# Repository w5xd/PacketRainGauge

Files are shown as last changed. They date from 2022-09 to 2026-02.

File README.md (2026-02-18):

# Packet Rain Gauge

This design is for a device that telemeters a packet when a magnet approaches, and
again when it retreats from a hall effect sensor. It consists
of a Printed Circuit Board (PCB) design, an Arduino sketch, and two variations on a funnel
that catches rain. One variant is a retrofit to install in a discarded rain gauge funnel
from an Oregon Scientific RGR126N Wireless Rain Gauge. If you don't 
have an RGR126N to retrofit, there is included  a 3D printable outdoor unit, which I designed
as a remix of this 
<a href='https://www.thingiverse.com/thing:4725413'>thingiverse rain gauge</a>.

This unit can telemeter to 
<a href='https://github.com/w5xd/PacketGateway'>an open-source packet gateway</a>.  Separately, or 
concurrently, this <a href='https://github.com/w5xd/WWVBclock'>WWVB clock</a> can monitor the packet
transmissions from this rain gauge. Or you derive your own design from the sources here. 

<h3>3D Print the Outdoor Assembly</h3>
The CAD directory in this repo has 3D 
models for the parts needed to all the outdoor parts.
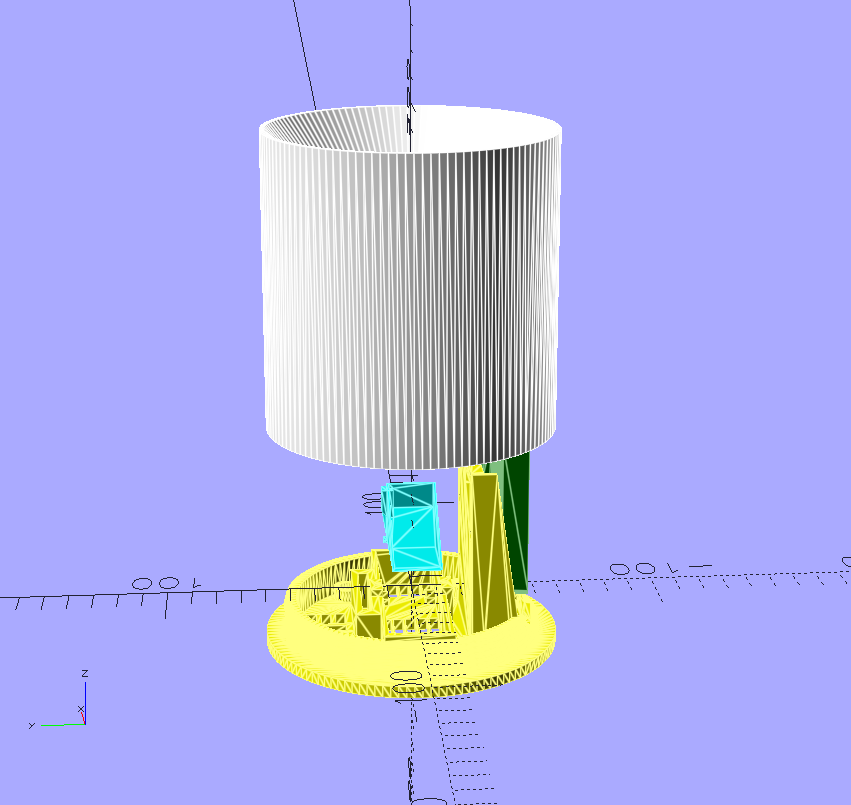
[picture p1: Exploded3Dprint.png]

STL files are downloadable from the <a href='https://www.thingiverse.com/thing:7052595'>thingiverse 7052595 posting of this remix</a>. 
All the STLs can be regenerated (or modified to your liking) using a combination of
OpenSCAD and FreeCAD. Each is open sourced and free.
The list of parts to print, starting with those designed with OpenSCAD is:
<ul>
<li><code>Pluviometer-base</code> (which requires the support enforcer <code>Pluviometer-base-supports</code>)</li>
<li><code>funnel-improved</code></li>
<li><code>Pluviometer-AA-print</code></li>
<li><code>bucket-improved</code></li>
<li>The flange I designed, <code>Pluviometer-flange-print</code>, fits snugly on the top of the T-profile steel fence post
I wanted to mount it. Unless you have the same fenceposts as me, you will have to use some other mount.
</li>
</ul>
The parts designed with FreeCAD are:
<ul>
<li><code>Placement-sensor enclosureBody001</code></li>
<li><code>Placement-sensor enclosureBody002</code></li>
</ul>

The PCB enclosure parts geometrically mate with both the Pluviometer-base, designed in OpenSCAD,
and the printed circuit board outline and hole pattern, which is available as a STEP model. The motivation for using FreeCAD
is that it can be configured to create a model that itself depends on both the OpenSCAD model of the base and bucket,
and the STEP model of the PCB. While the
FreeCAD method for a dependency on a STEP model is simply its File/Import method, FreeCAD has a not-quite-obvious
workflow for modeling dependencies on an STL mesh. Follow FreeCAD's File/Import of the OpenSCAD STL with
its Parts Workbench "Create Points From Geometry" method. The resulting points object can then be used
to create DatumPoint and DatumPlane references that can, in turn, be referenced in Sketches. The caveat is that this workflow
does not automatically accommodate subsequent changes to the OpenSCAD design. That is, any subsquent change in the OpenSCAD
design requires the FreeCAD model to be completely recreated manually.

<h3>Oregon Scientific Retrofit</h3>
The original Oregon Scientific rain gauge mechanical design is a funnel that directs rainfall into a rocker
that is centered below the funnel. The rocker (called a "bucket" in the thingiverse design) has two identical cups arranged on a see-saw. After 1mm
of rainfail, the higher cup has enough weight to rock the see-saw. The higher
one falls to become the lower one and dumps its water from the now lowered cup. The new position leaves 
the opposite
cup&mdash;which was empty&mdash;under the funnel. It begins to fill with new rainfall and the process repeats. In the middle of the
rocker&mdash;centered, which means it does not affect the center of mass between the two cups&mdash;is a magnet. 
The PCB detects the magnet swinging
by. 

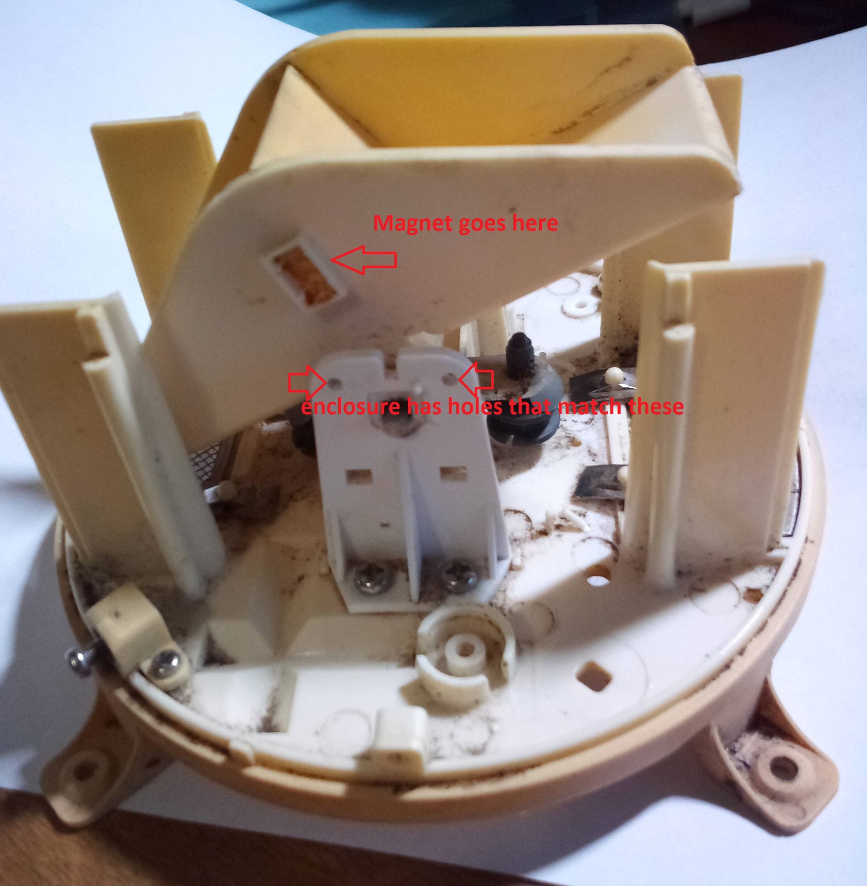
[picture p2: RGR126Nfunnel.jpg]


The RGR126N design sensed the passing of the magnet using a reed relay. Such a relay has ferro magnetic 
contacts that close as
the magnet is in proximity. The original relay sensor was positioned for closest approach 
to the relay
as the rocker passed top dead center
in both directions, which means the rocker was moving relatively quickly as the relay sensed it.  

A hall effect magnetic sensor is used in this design instead of a reed relay. The Si7210
version of the PCB, sketch, and sensor can
easily be programmed to separately detect the arrival and the departure of the magnet from
proximity to the sensor. (A non-programmable AH1383 sensor can be substituted.)
The geometric desgin positions the sensor
in close alignment with the rocker <b>at its resting position</b> with one
cup down&mdash;the left one in the photo above. Its Arduino
sketch is programmed to separately report the arrival and departure of the rocker, sending a packet for
each. The new magnet is mounted in the same recess in the rocker as the old magnet. 
The needed magnet is slightly heavier than the original: about 0.5g as
opposed to 0.3g on my scale, so a calibration check is in order before putting it into service.
The result is this design sends packets at (almost) the same rate per volume of rainfall
as the old one, just not quite at the exact same rocker positions.

Silicon Labs publishes a detailed discussion about magnets&mdash;including details
about this exact scenario: replacing a reed relay with a hall effect sensor&mdash;about how the
magnet axis and sensor geometry are related: 
<a href='https://www.silabs.com/documents/public/application-notes/an1018-si72xx-sensors.pdf'>
https://www.silabs.com/documents/public/application-notes/an1018-si72xx-sensors.pdf<a>.
A K&J Magnetics B422 magnet conveniently matches the original magnet's dimensions to
fit in the original rocker, and has its
poles aligned so that its
pole axis as required to penetrate the IC sensor when mounted in the original rocker.

The original water tight
battery compartment is retained, but after removing the PCB that shares the
battery enclosure. This upgrade runs on two AA cells just like the original. I had
no luck running the Oregon Scientific device using lithium AA cells, but this design works
well with them and gets the much longer battery life with the lithium cells'
 much larger Ampere-hour capacity compared to alkaline.

This retrofit parts list is:
<ul>
<li> The original funnel's plastic parts minus the two PCBs, and with the
original magnet removed from the rocker. It was glued in place and a small screwdriver can pry it out.
<li> The PCB as documented in this repository. It mounts the Arduino, 
a TMP175 sensor, and an RFM69 packet radio module. Gerber files are <a href='./PCB'>here</a>.
<li> A <a href='https://www.kjmagnetics.com/proddetail.asp?prod=B422'>K&J Magnetics B422 neodymium magnet</a>. 
dimensions are 1/8" x 1/8" x 1/4" which fit into the same mounting hole on the original rocker.
Note there is a required orientation of the new magnet that takes some care when
you glue it. See <a href='#MAGNET_ORIENTATION'>below</a>.
<li> A 3D printable enclosure that mounts on the same hole pattern
as the one of the original PCBs&mdash;the one facing the magnet on the rocker.
<li> Two AA cells inside the original plastic battery compartment. The
battery's original ribbon cable is replaced with just a pair. +3VDC and GND wires are routed 
to the replacement PCB. This design can use either
alkaline or lithium cells. 
</ul>

<h2>Arduino sketch</h2>
The <a href='PacketRainGauge/PacketRainGauge.ino'>sketch</a> sends a packet to the Packet Gateway every time the 
magnet on the rocker arm either arrives at, or departs from the
sensor. The message
packet also contains a battery voltage measurement, the TMP175
reading, and other details. The sketch also sends a packet after
a timed interval absent any rainfail, which enables battery level
monitoring at the gateway. The timed interval is settable, and
once per 24 hours is enough. The temperature reading at the funnel is 
useful mainly for
monitoring the condition of the funnel assembly. Direct
sunlight on the funnel makes its value not representative
of ambient air temperature because the funnel must be 
mounted in the open to be useful as a rain gauge.
<br/><br/>
The gateway's processing of the rainfall messages is not part of this
repository. See the repository at https://github.com/w5xd/diysha for
an example. In that project, the receipt of rainfall packets writes a
text file that, in turn, can be read by the "bins" feature in <a href='http://www.gnuplot.info'>gnuplot</a>.

<h2> Construction</h2>
Both variations use the same electronics and custom PCB.
The <a href='https://www.sparkfun.com/products/11114'>Arduino Pro Mini</a> requires the 
following of its hardware options to be made in order to work 
in this project:
<ul>
<li>The 3.3V version of the Pro Mini is <b>required</b> (<i>i.e.</i> not the 5V version.)
<li>Jumper SJ1 (top side, close to the GND pad) must be desoldered to remove the red power LED's power drain.
<li>The bottom side i2c pullup positions, R1 and R3, can each have a 4.7K 
resistor installed. Two SMD 0603 size resistors just fit inside a hole
in the PCB designed to clear them. Alternatively, REV02 and higher of the PCB has positions for SMD
0805  pull up resistors that are not quite so tiny.
</ul>

PCB Parts for PCB version 3 and later
<ul>
<li>Sparkfun Arduino <a href='https://www.sparkfun.com/arduino-pro-mini-328-3-3v-8mhz.html'>Pro Mini</a> in 3.3V
<li>Sparkfun <a href='https://www.sparkfun.com/rfm69hcw-wireless-transceiver-915mhz.html'>
RFM69HCW</a></li>
<li><a href='https://www.silabs.com/documents/public/data-sheets/si7210-datasheet.pdf'>Si7210-B-04-IVR</a> I2C Hall effect sensor in SOT-23-5 package or...<br/>
<a href='https://www.mouser.com/datasheet/3/175/1/AH1381_AH1382_AH1383.pdf'>Diodes Incorporated AH1383</a> in SOT-23-5</li>
<li><a href='https://assets.nexperia.com/documents/data-sheet/74HC_HCT1G86.pdf'>SN74HC1G86</a> Single 2 input XOR in SOT753 package</li>
<li><a href='https://assets.nexperia.com/documents/data-sheet/74HC_HCT1G02.pdf'>SN74HC1G02</a> Single 2 input NOR in SOT753 package</li>
<li><a href='https://assets.nexperia.com/documents/data-sheet/74HC_HCT1G14.pdf'>SN74HC1G14</a> Single Schmidt inverter SOT753 package</li>
<li>TMP175 temperature sensor in 8 SOIC package
<li>10M resistor size SMD 1206
<li>2.7K resistor size SMD 1206
<li>2 by 4.7K resistors size SMD 0805
<li>3 by 10uF 10V tantalum or ceramic in SMD 1206
<li>.1uF ceramic 16V in SMD1206
</ul>

Mouser <a href='https://www.mouser.com/Tools/Project/Share?AccessID=1e16e65a5d'>Project</a> referencing all the above PCB parts.

<h3>Si7210 end-of-support and the AH1383</h3>
Silicon Labs has announced end of support for the Si7210. The Diodes Incorporated AH1383
is supported as a substitute on the PCB and sketch. It solders onto the same pads as the Si7210, except
the SDA/SCL lines for I2C have no connection to the AH1383.
The AH1383 happens to fit on the same solder pads as the si7210.

<h3>PCB considerations</h3>
Mount the Arduino directly to the PCB without headers. 
To ensure the pads on the Arduino do not connect to the vias on the PCB, cut a piece
of paper roughly .3" wide and 1" long. Insert this paper as an insulator between
the Pro Mini and the PCB while soldering header terminals between the PCB and
the Arduino. It may be left in place or pulled out after soldering

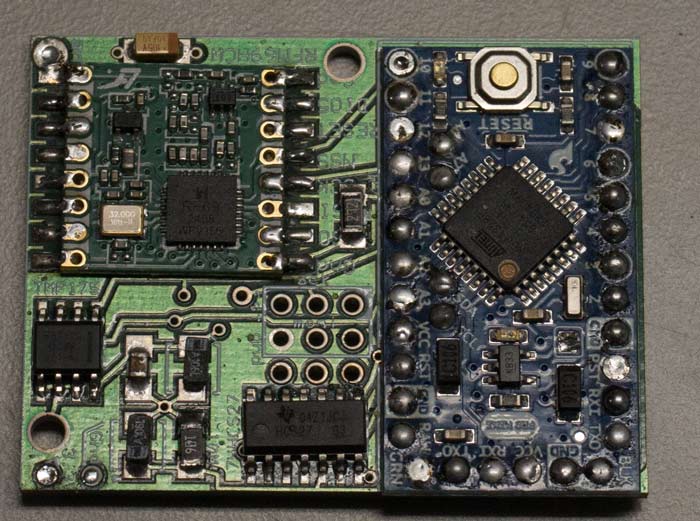
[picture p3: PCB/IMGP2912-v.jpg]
PCB top


Its important to:
<ul>
<li>center the Arduino on its holes in order to clear the I2C resistors mounted as above. 
<li>minimize the solder bumps on the bottom side of the PCB so the assembly will 
fit in the enclosure. I set the PCB on a flat surface, laid the Arduino board on top,
then inserted headers from the top and soldered from the top first, so the pins just
reach the bottom of the main PCB.
</ul>

The replacement PCB layout is optimized to be as small as possible while 
retaining the ability for an ordinary human to place the parts and solder them.
I used a <a href='https://whizoo.com/'>home brew SMD oven</a>, but steady hands can alternatively 
solder them one pin at a time.

The PCB circuit diagram is <a href='PCB-circuit.pdf'>here</a>.

The hall effect sensor is mounted to the <i>bottom</i> of the PCB. (REV01 shown, later revisions
look similar.)
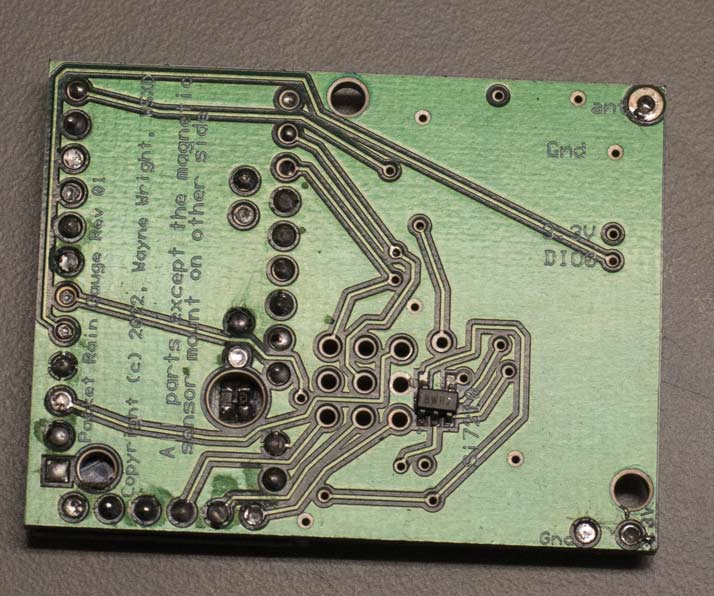
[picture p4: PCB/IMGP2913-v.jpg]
PCB bottom

This is the only part on the bottom.
I used an SMD oven to mount it first (and nothing else in the oven with it.) After it cooled off, 
I flipped the board over
and used the oven again to bake the top side SMD parts. While the ExpressPCB process provides
a solder paste mask in its gerber files, I found it easier just to use a very small stick of some sort
(a 0.050" allen key, for example) to dab tiny bits of paste on the solder pads.
The RFM69 is documented to be
oven-safe, but I have destroyed at least one (maybe not because of the oven?) and its
easy enough to hand solder its 100 thou wide solder pads.
<br/><br/>
Setting up the Arduino requires programming the part, and also requires 
serial port commands to configure the radio parameters.  Connecting to the Pro Mini's
serial port is a bit of a trick because the enclosure cannot accommodate a standard
0.100" header soldered onto the board. One option is to solder on a header, program
the sketch, set its parameters through the same serial port header,
 and then cut the header off to install the Arduino in its enclosure.
Alternatively, the PCB has
 a hole pattern that enables  a pogo adapter to access either 
the standard ISP
programming header on the Arduino Pro Mini, or, in a non-standard layout, the
Arduino's serial port.

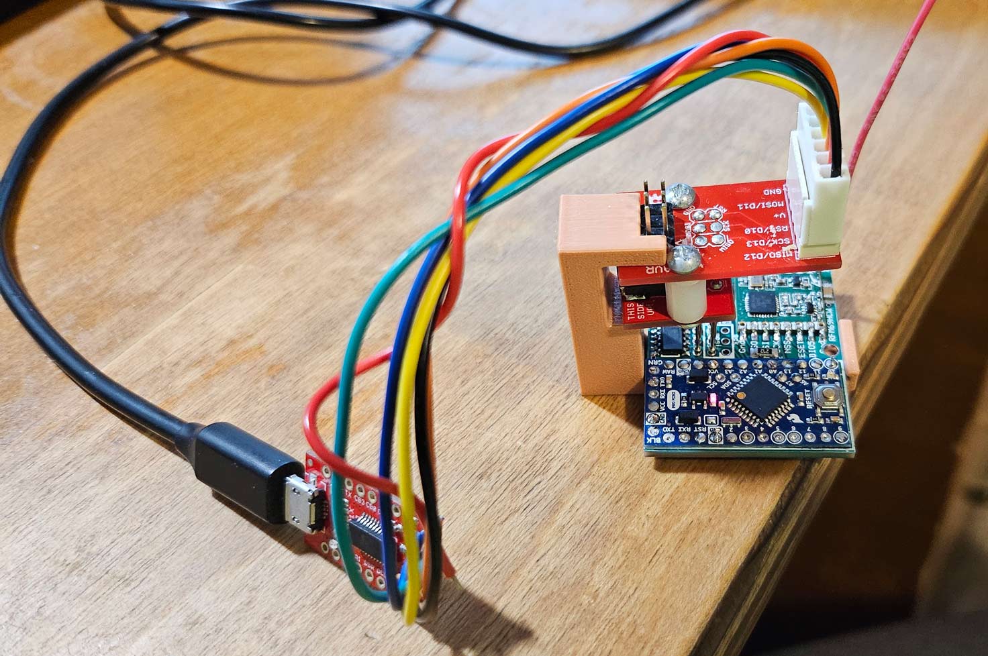
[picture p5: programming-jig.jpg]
programming-jig


The serial port pin layout on this PCB is 3 extra pins alongside the standard 6-pin ISP header.
I custom assembled a <a href=''>SparkFun ISP Pogo Adapter</a> with an FTDI USB serial breakout
to access the Arduino serial port this PCB. It can be used both to program
the CPU, and to set its configurable parameters. Be sure
you wire the 3.3VDC to the pogo! The RFM69 will be destroyed if you 
apply 5VDC.

Position the serial port pogo
on the 6 pins aligned along the nearest edge of the PCB, and it connects to the Arduino's
serial port pins. The Pogo adapter as supplied
has no connector on the ends of its wires. You can solder them to, for example,
the <a href='https://www.sparkfun.com/products/13263'>SparkFun FT231X Breakout</a>.
Note that on this particular FT231X breakout, you <b>must</b> change the power jumper to
make it supply 3.3V, else you'll fry the RFM69 on your first try.

The CAD directory has a 3D model for a jig that fits the PCB and the Pogo adapter
that frees your hands while accessing the serial port on the PCB.

The Pogo Adapter has 6 wires. When positioned for access to the Arduino serial port,
the wires are <i>not</i> as labeled on the Pogo board, but are as follows on the PCB's
Arduino:
<ol>
<li>black. 3.3VDC. <i>Not</i> 5V, which will destroy the RFM69.
<li>red. MOSI. Leave open. Only 5 wires are connected for serial port access.
<li>orange. GND
<li>yellow.  RXI on Arduino. To TXD on break out.
<li>green. TXO on Arduino. Goes to RXI on break out.
<li>blue. DTR on Arduino. DTR on the break out.
<li>To match the Arduino-to-Serial-breakout standard wiring, you also must put a
jumper directly on the break out between its ground and CTS.
</ol>

A Pogo adapter wired as above to a serial break out can be used both to
program the Arduino, and to use a terminal application for serial port
commands to configure the packet radio parameters. A different Pogo 
adapter can also be used posititioned to its standard wire assignments
to program the Arduino on its ISP port, but the radio parameters
can only be configured through the serial port.

<h3>Enclosures</h3>
Both PCB enclosure designs, the retrofit and the full outdoor unit, have a two
part 3D printable shell to house the custom PCB. 
For the retrofit, its base has three mounting holes matching the original rocker-mounted PCB. 
For either design, there are three holes
for these wires: one each for the radio antenna, ground, and 3.3V. 
Once the Arduino is configured, use a silicon sealant
on the joints between the base and cover, and also to seal the wire holes.
Consider the enclosure as disposable. If you use a silicon rubber sealant,
you might be able to use a box cutter to open it if you need to reprogram
the Arduino. But plan to 3D print a replacement enclosure should you ever
open it.
On the retrofit, I substituted #4 brass wood screws for the original steel screws that held
the PCB inside the funnel assembly, because I suspected that the strong
magnet attraction on them might chage the mechanical balance of the rocker
 and thus change the calibration.
<br/><br/>
The full outdoor unit needs the following commercially available parts to house
the dual cell AA battery:
<ol>
<li> <a href='https://www.mouser.com/ProductDetail/12BH222-GR'>Eagle Devices 12BH222-GR</a>. If you try to substitute a 
part be careful
with the width. The 12BH222 is comparatively narrow, and
just fits inside the AA holder 3D printed part.
<li>Quantity two by AA cells. Lithium cells are preferred. They should last over 12 months.
<li> A <a href='https://www.kjmagnetics.com/proddetail.asp?prod=B422'>K&J Magnetics B422 neodymium magnet</a>.
The same part as the retrofit, above. Note there is a required orientation of the magnet that takes some care when
you glue it. See <a href='#MAGNET_ORIENTATION'>below</a>.
<li> <a href='https://www.mcmaster.com/catalog/131/4021/2418T16'>3/32" width, Dash Number 141 O Ring (2 1/2" OD)</a>
The O ring seals the battery compartment against water.
<li> Quantity 7 #3-48 x 3/8" socket head screw. (#2-56 x 3/8" socket head also fits the 3D print)
<li> Quantity 7 #3-48 hex nuts. (#2-56 nut also fits the 3D print)
<li> The base/flange mount 3D parts have holes for quantity four #8-32 x 3/4" socket head screws and matching 8-32 hex nuts
</ol>

When assembling the two enclosure halves together (Body001 and Body002) with the PCB in between as a 
sandwich, it shoud not be possible to squeeze them tightly enough to permanently actuate the RESET switch
built into the Sparkfun Arduino Pro Mini. But check it. It won't telemeter and it will run
down the battery in about 24 hours.

<h3 id="MAGNET_ORIENTATION">Magnet Orientation</h3>
The B422 magnet's 1/4" dimension fits into the rocker mount in the obvious 1/4" slot dimension. 
But that constraint still leaves
four 1/8" sides of the magnet that might face the sensor. <b>Only one works. The
South pole of the magnet must face the sensor!</b>
(well, the Si7210 can be programmed to work if the North pole is instead facing
the sensor.) The magnet must be chosen and positioned to exceed the turn ON threshold
of the sensor.
<a href='MagnetOrientation.md'>See details here.</a>

<h3>How many signals per inch of rain?</h3>
The original Oregon Scientific part, by my observation, sends an update every 1mm of rainfall. In the retrofit,
I measured the device to send an update about every 1.2mm of rainfall. I attribute the difference
to the extra weight of the B422 magnet compared to the original (as nothing else has changed.)
The full outdoor unit, as <a href='https://www.thingiverse.com/thing:4725413'>documented by its original designer</a> 
clicks every 0.15mm of rain. As of the latest update to this repository, a 1/4" hex weighting nut is added
to the rocker to make the water volume more consistent, and to require more water to rock it. 
I measure 0.38mm of rain per click. Your mileage may vary. 
<br/><br/>
What is the highest rainfall rate that can be telemetered? There are at least two different
parts of this design that might limit the highest rate: (a) water pouring through the funnel
so fast that it rocks the bucket by force of the pouring water instead of the designed behavior, which
tips the bucket when only the weight of the water in the upper bucket overcomes the weight of the empty bucket,
and (b) the electronics has a fastest rate it can detect movement (the sensor manufacturer documents
it at 5 samples per second) or telemeter it (the RFM69 packet
radio.) I have not attempted to measure either of these, nor brainstorm any additional rate limits.
However, I have measured that the on-the-air length of a packet is under 3 milliseconds. 
And I have observed that the system reliably telemeters 1 packet every 3 seconds as the calibrated cylinder
calibration test begins.
The actual limit is likely much faster than that.  A bucket dump every 3 seconds
corresponds to a rainfall rate of about 7 inches per hour. 
If your raingauge
experiences more than 7 inches per hour and you are in the vicinity, then you have more serious problems than 
whether your raingauge can keep up.

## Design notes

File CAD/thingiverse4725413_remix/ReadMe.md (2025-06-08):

This is a modified version of https://www.thingiverse.com/thing:4725413

My magnet of choice is of dimensions 1/4" x 1/8" x 1/8" as described in 
this repo's root directory.
My sensor of choice is the hall effect as described in this repo's root directory.

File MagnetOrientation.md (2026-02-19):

<h1>Magnet Orientation</h1>
The B422 magnet has two faces perpendicular to its pole axis and I'll call the other two
"sideways." Another
magnet with known poles can figure out which face is right: the face that sticks to 
the other magnet IS one of the poles. Here
are some more hints: <a href='https://www.kjmagnetics.com/products.asp?cat=163'>
https://www.kjmagnetics.com/products.asp?cat=163</a>.  For the AH1383, the South pole
must face the PCB.
<br/><br/>
You can also use the assembled
PCB and sketch to read out the magnetic field with the magnet close. When oriented properly,
it will read the maximum negative magnitude about +16000. 
Use the sketch's <code>ReadModeForSeconds</code> command to
make the magnetic field print out continuously. Hold the magnet directly over the Si7210 and then
slide it only 1/8" or so in the 2 directions perpendicular to the magnet.
If you have a pole directly facing the sensor (the 
desired orientation) the sign will not change on the magnetic field. If you have a unipolar
sensor (AH1381) with the correct (South) pole, facing it, stays at +1 at (nearly) equal distances in
all directions from centered over the sensor. With the wrong pole, it reads out 0 and nothing happens at all
as you move the magnet away from the center of the sensor.
If you have an edge toward
the sensor ("sideways"), the sign will change right where the magnet is centered over the sensor. 
The AH1383
version of the sketch also supports the <code>ReadModeForSeconds</code> command, but it
only reads out +1 (for the magnet "close") and 0 for the magnet "far." You need the magnet
oriented so its reads +1 on the AH1383 when centered over the sensor.

<h2>AH1383 thresholds: 45 Gause on, 35 Gause off</h2>
The Si7210 version of this build is especially useful for experimentation because the sketch can
be set for a wide range of on and off thresholds and can be made to operate either omnipolar
or unipolar. However, that part might not be available. The AH1383 has built in thresholds,
on at 45 Gause, and off at 35 Gause, which must
be compatible with the actual magnetic fields of the chosen physical magnet and geometery.
This section describes that calculation. <br/><br/>
The 3D printed rocker and sensor are spaced with the magnet and sensor about .15 inches apart
along the N/S axis of the magnet, which is the Y dimension in the graph below. The rocker moves
the magnet between two positions at X = 0 (magnet and sensor aligned) to about X = .42 inches
where the rocker rests against the opposite stop. The magnetic field calculations are from  
<a href='https://www.kjmagnetics.com/magnetic-field-calculator.asp'>https://www.kjmagnetics.com/magnetic-field-calculator.asp</a>.
Here is what the magnet/sensor geometry looks like for a properly installed magnet and with the
rocker directly under the magnet:
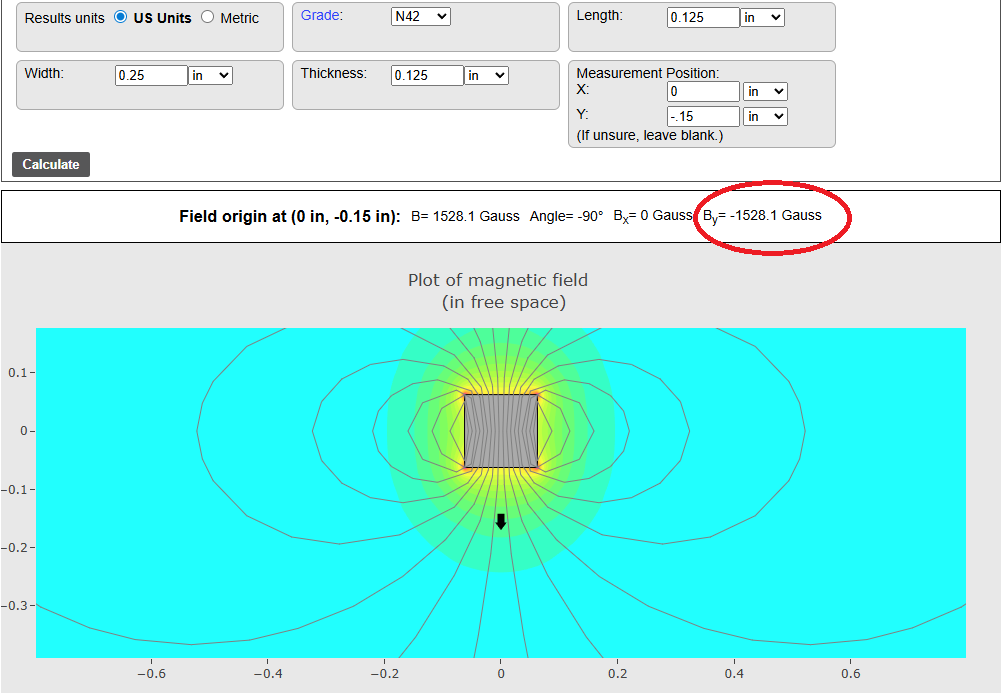
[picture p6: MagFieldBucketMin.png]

The next graph below shows that this particular magnet need move only a few thousanths of an inch around the
point X=.177 inches for the B<sub>Y</sub> field shift signs, which is where the
amplitude moves through both the ON and OFF thresholds of the part. X=.177 is not quite half
way through the rocker movement with top dead center at X=.42/2 = 0.21 inches. With the magnet installed properly
the sensor position is indicated by the arrow in the screen shots, and the magnet on
the rocker moves left and right across the field as graphed here.
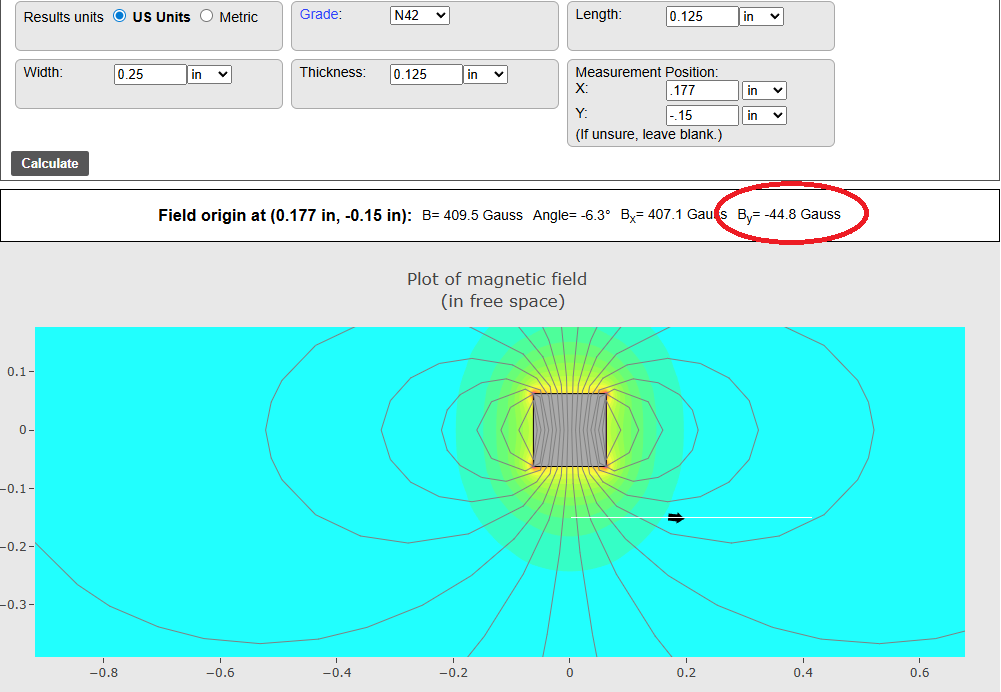
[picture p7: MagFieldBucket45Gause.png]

The AH1383 is unipolar, which is important because with the rocker at the far stop, as 
shown below, 
the amplitude of the magnetic field has magnitude above the 35 or 45 Gause threshold,
but of the opposite sign. (Parts specified as "omnipolar" will trigger above a
threshold amplitude of either sign. They won't work here.)
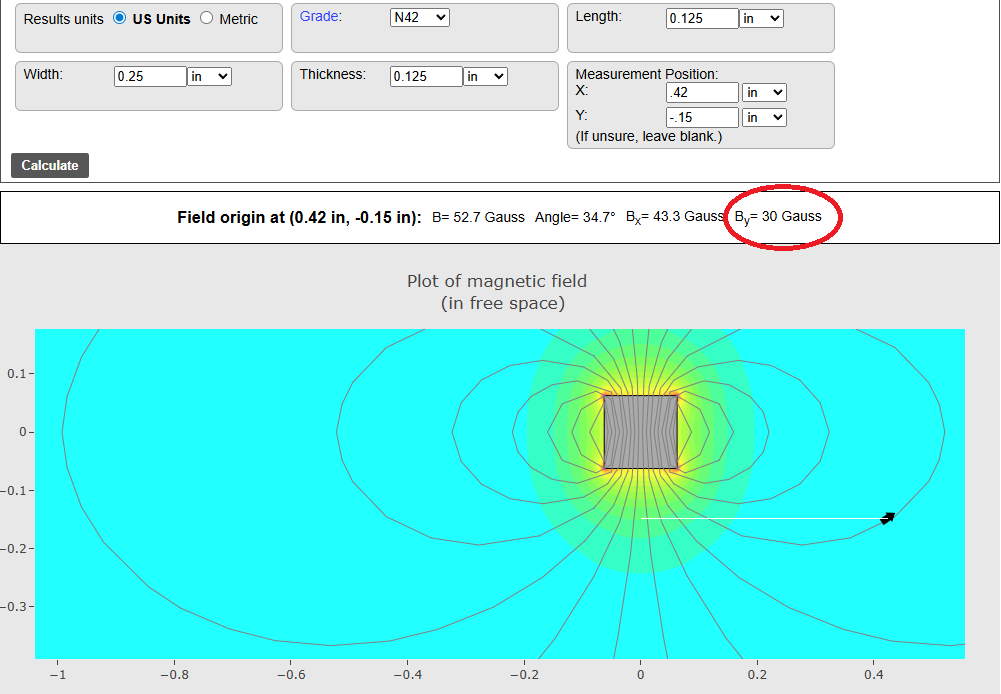
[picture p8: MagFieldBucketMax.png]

As can be seen from the graphs above, the parts AH1382 and AH1381 are suitable substitutes
for the AH1383 specified for this build. The -82 and -81 parts have smaller thresholds,
but, because all the parts in this series are unipolar, and because the field is of opposite
polarity on opposite ends of the rocker travel, all the parts should work and
will switch states very close to the X=.177 point where the field polarity reverses. 
A backwards magnet will get the same field amplitudes, but in opposite polarity, which
means only the AH1381 has any hope of turning on, and then only when the magnet is
as far as possible from the sensor. Backwards won't work.
<h4>Sideways magnet calculation</h4>
The field calculator can also be used to predict what will happen if the magnet is incorrectly
installed
"sideways." Spoiler alert: it won't work. Sideways means the magnet is with its N/S pole axis along 
the face of the rocker as opposed to facing
the sensor. To calculate that behavior, reverse the X and Y everywhere they appear in the calculator. 
The sensor position in this graph is at the arrow as in the graphs above, but moves up and down as the rocker moves.
The calculator predicts zero amplitude B<sub>X</sub> at X=0 (not graphed--the answer is zero),
peaking at about X=0.1 inch 
with about 700 Gause (also not graphed), and dropping down to about 40 Gause at the far rocker rest stop of X=0.42.
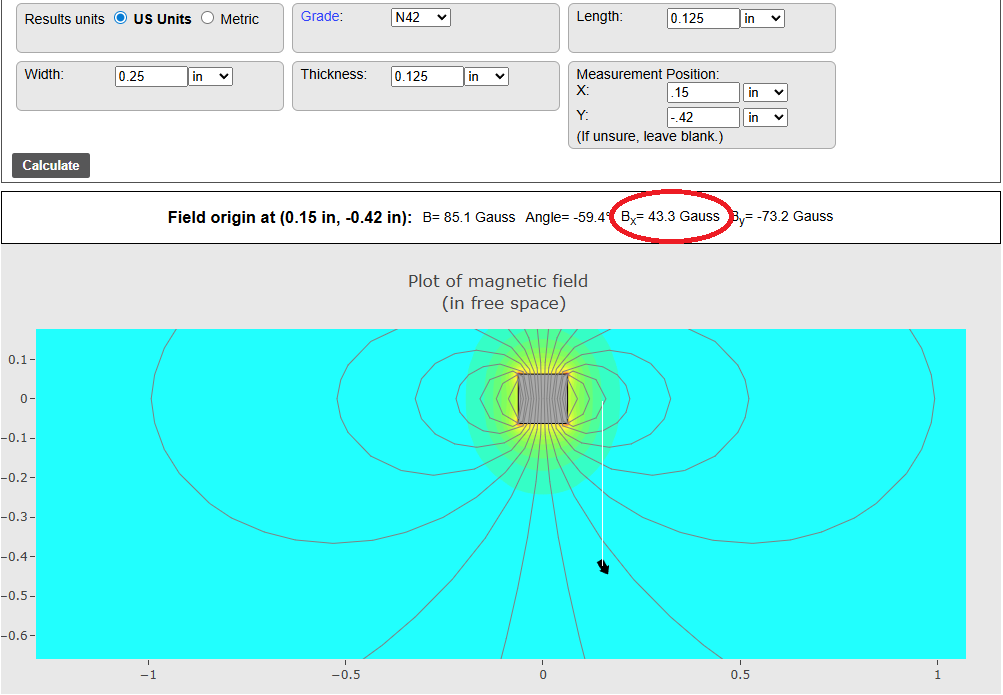
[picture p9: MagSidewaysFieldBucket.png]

Slight movement of the rocker around X=0 will move the field both above the ON threshold and below the
OFF threshold. Therefore, multiple redundant signalling the rocker around X=0 can be expected. This
applies to both possible incorrect sideways orientations. (Only the polarity of the field at the
sensor is reversed with respect to the other sideways orientation.)
<h2>Sketch parameter setup</h2>
All the magnetic field calculations in the previous section apply to the Si7210, but
the Si7210 and its sketch have many programmable settings for 
thresholds and polarity. That is, the Si7210 can support
a much wider range of magnet strengths and geometry. In the physical designs presented here, it means
smaller magnets can be used than specified, and the N/S axis orientation can work in two
directions, rather than just the one that the AH1383 must see.
Th sketch parameter advice here applies to both physical arrangements, the Oregon Scientific funnel retrofit, and 
3D printable design presented here. 
<ul><li>Mount the magnet with either its N
or S pole facing the sensor as described in the previous section.</li>
<li>The recommended Si7210 interrupt threshold and hysteresis settings are a relatively
low magnitude (1500 out of a maximum of 16000) and small hysteresis (8 out of 1792). The commands
are:
<pre>
<code>SetSWOP 0x64
SetSWHYST 0
</code></pre></li>
<li>The Si7210 interrupts per the previous item, but the chip's interrupt output does not
directly correspond to the magnet position. The sketch, therefore, is coded to originate
a notification of a rocker move based on the magnetic field going outside the range
specified as below. 
<pre>
If the North pole faces the sensor:
<code>SetNearThreshold 1500
SetFarThreshold 0
SetSignedThreshold 0
</code>If the South pole faces the sensor:<code>
SetNearThreshold -1500 <i>Note it is negative</i>
SetFarThreshold 0
SetSignedThreshold 1
</code>
</pre>
The NearThreshold and FarThreshold are signed, and need to be different based on the
magnet orientation. The OP and HYST values in the Si7210 are not signed, and do not
depend on the magnet orientation.
</li>
</ul>
The sketch, per the above settings, is waked up by any motion of the magnet around the value 1500,
and then polls the magnetic field looking for it to go outside the range NearThreshold and FarThreshold.

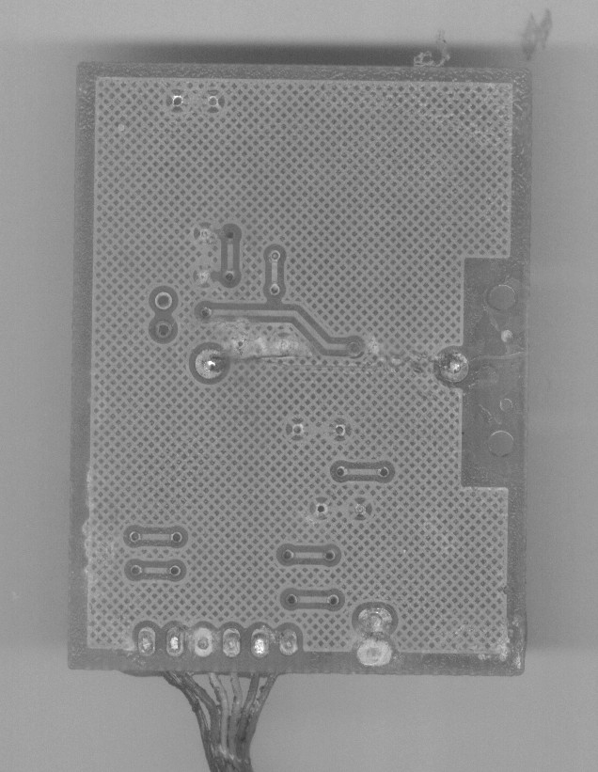
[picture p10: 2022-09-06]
CAD/rain-funnel-sensor.jpg

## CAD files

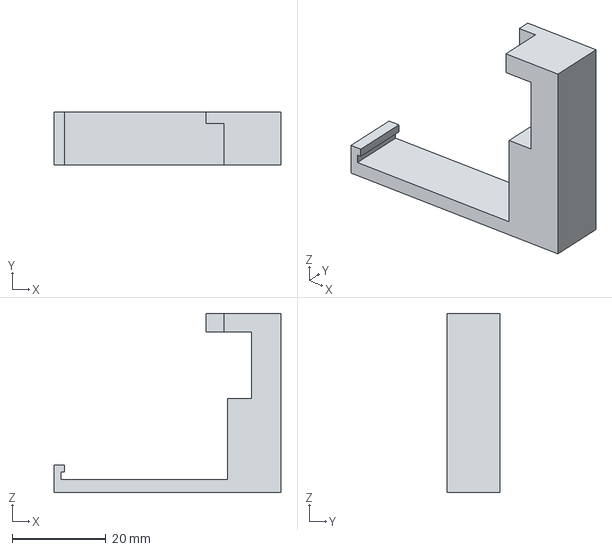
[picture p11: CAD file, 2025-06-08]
CAD/jig-PartBody.step
48.5 x 11.4 x 38.4 mm

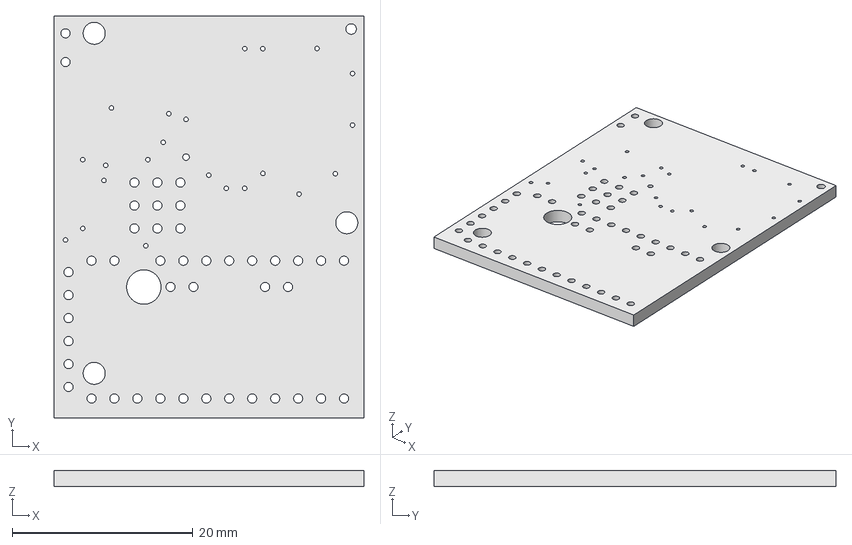
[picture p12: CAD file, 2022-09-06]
CAD/pcb-Body.step
34.3 x 44.5 x 1.78 mm

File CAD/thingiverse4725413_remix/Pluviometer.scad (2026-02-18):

/* This thing is modified from https://www.thingiverse.com/thing:4725413
** (c) 2025 by Wayne E Wright, https://www.thingiverse.com/wwrr55 
**
** The sources to the 3D models, the Arduino sketch, 
** the printed circuit board, etc. are published on github at https://github.com/w5xd/PacketRainGauge
** The 3D printable STL files are published on thingiverse (and not on github).
**
** While the overall structure of the 4725413 scad file, Pluviometer.scad, is retained, none of the parts
** here is compatible with printed versions of the original. Each has been modified in
** some way from the original.
**
** The bucket is modified to accept a different magnet, 1/4" x 1/8" x 1/8"
** The threaded base/funnel joint is now implemented with the standard threads library: https://github.com/rcolyer/threads-scad
** The sensor and sensor_back are removed this implementation.
** The base is modified to have a built-in dual AA cell battery bracket.
** AA cell holder to match the bracket is added.
** A flange to mate a certain T-post steel fence post is added.
**
** A companion FreeCAD file contains a design to place a hall effect sensor PCB
** at the base's sensor slot.
*/
use <threads.scad>

cable_holder = false;

view_as_assembled = 1; // [1:as assembled, 0:expoloded, 2:XZ cross section, 6:XZ' cross section, 3:YZ cross section, 4:3D print, 5:intersect base&AA]
show_base = true;
show_base_supports = false;
show_flange = false;
show_cellAACover = true;
show_bucket = true;
show_funnel = true;

funnel_height_mm = 120;
funnel_inner_height_mm = 70;
funnel_tip_id_mm = 5; //[0.1:.1:10]
funnel_tip_wall_thick_mm = 1; // [0.1:.1:5]
funnel_strainer_z_thick_mm = 0; // [0:.1:3]
funnel_strainer_horz_thick_mm = 1; // [0:.1:3]

base_diameter_mm = 120;

number8MachineScrewBoltHoleDiameter = 25.4 * .18;
number8MachineScrewSocketHeadDiameter = 25.4 * .285;
number8MachineScrewSocketHeadHeight = 25.4 * .17;
number8MachineNutHeight = 25.4 * .135;
number8MachineNutAcrossFlats = 25.4 * 11 / 32;

base_funnel_thread_diameter_mm = 105;
base_funnel_thread_height_mm = 14;
base_funnel_thread_pitch_height_mm = 2.5;
base_mount_hole_diam_mm = number8MachineScrewBoltHoleDiameter;
base_disk_thickness = 5;

bucket_width = 70;
bucket_z_height = 25; // [22:.1:40]
bucket_display_rotation = 0;
bucket_inner_triangle_fill_width = 25;
bucket_inner_triangle_fill_height = 15;
bucket_hex_insert_flat_mm = 0.1; // 11.1 for 1/4" nut
bucket_hex_thickness_mm = 5.5;
bucket_hex_surround_mm = 1.1;

fnval = $preview ? 12 : 120;
fn30val = $preview ? 10 : 30;
$fn = $preview ? 12 : 120;

module __x__ () {} // stop the OpenSCAD customizer here

bucket_slot_width_mm = 24;
bucket_y_width_mm = 20;
bucket_z_thickness_mm = 1;
bucket_y_thickness_mm = 1;
bucket_x_thickness_mm = 1;

flange_start_z_mm = -23;
flange_fastener_diameter_mm = 18;
flange_fastener_height_mm = 3;
flange_transitionmm = 25.4 * 1.5;
flange_post_overlap = 25.4 * 1.5;
flange_post_cut_depth = 25.4 * 2;

tan30squared = tan(30) * tan(30); // for converting nut "across flats
acrossFlatsConvert = sqrt(1 + tan30squared);

module triangleRa(a, angle, h, c){
  rotate([90, 0, 0])
  linear_extrude(height = h, center = c, convexity = 10)
  resize([a, a*tan(angle)])
  polygon([[0,0], [1,0], [0,1]], paths=[[0,1,2]]);
}

module triangleI(x, y, z, c){
  rotate([90, 0, 0])
  linear_extrude(height = y, center = c, convexity = 10)
  resize([x, z])
  polygon([[-1,0], [1,0], [0,1]], paths=[[0,1,2]]);
}

module bucket_hex(outer = true)
{
  if (bucket_hex_insert_flat_mm > 1)
  {
    n = 6;
    inc = 360 / n;
    hex = [for (s=[0:1:n-1], a = (inc/2) + s * inc) [cos(a), sin(a)]];
    r = (bucket_hex_insert_flat_mm * 0.5 / hex[0][0]);
    translate([0,-(bucket_y_width_mm-bucket_hex_thickness_mm-bucket_hex_surround_mm)/2, bucket_z_height - r - 3*bucket_hex_surround_mm])
    rotate([90,0,0])
      {
        if (outer)
        linear_extrude(h=bucket_hex_thickness_mm + bucket_hex_surround_mm, center=true)
          offset(bucket_hex_surround_mm) 
            polygon(hex * r);
        else
        translate([0,0,bucket_hex_surround_mm])
          linear_extrude(h=bucket_hex_thickness_mm + bucket_hex_surround_mm, center=true)
            polygon(hex * r);
     }
  }
}

module bucket(){
  one4 = 25.4 * .25;
  one8 = one4 * .5;
  magClearance = .008 * 25.4;
  magY = bucket_y_width_mm/2 - 1;
  magZ = 18;
  color("cyan")
  difference(){
    union(){
      bucket_hex(true);
      difference(){
        triangleI(bucket_width, bucket_y_width_mm, bucket_z_height, true);
        translate([-bucket_width/4-bucket_x_thickness_mm/2, 0, (bucket_z_height+bucket_z_thickness_mm)/2]) 
          cube([bucket_width/2, bucket_y_width_mm-bucket_y_thickness_mm*2, bucket_z_height-bucket_z_thickness_mm], center = true);
        translate([bucket_width/4+bucket_x_thickness_mm/2, 0, (bucket_z_height+bucket_z_thickness_mm)/2]) 
          cube([bucket_width/2, bucket_y_width_mm-bucket_y_thickness_mm*2, bucket_z_height-bucket_z_thickness_mm], center = true);
      }
      // centering the bucket
      linear_extrude(height=1)
        square([5, bucket_slot_width_mm-.9], center=true);

      // magnet outer
      magOuterDx = one8 + one8;
      magOuterDy = one8 + one8/2;
      magOuterDz = one4+one8;

      magOuterYZProfile=[[magOuterDy/2, -magOuterDz/2], 
                [magOuterDy/2, magOuterDz/2],
                [-magOuterDy/2, magOuterDz/2],
                [-magOuterDy/2, -(magOuterDz + one4 + one8)/2]];
      translate([0, magY + one8/4, magZ])
      rotate([90,0,90])
      linear_extrude(height=magOuterDx, center=true)
          polygon(magOuterYZProfile);
    
      triangleI(bucket_inner_triangle_fill_width, bucket_y_width_mm, bucket_inner_triangle_fill_height, true);

      }
    
    // pivot shaft hole
    translate([0, 0, 3]) rotate([90, 0, 0]) cylinder(d=3.25, h=bucket_y_width_mm, center=true, $fn=fn30val);
    bucket_hex(false);
    // magnet inner
    translate([0, magY, magZ])
    translate([0,one8/2])
      cube([one8 + magClearance      , one8+.05       , one4 + magClearance], center=true);
  }
}

// AA battery holder dimensions
/* The profile of the AA cell holder is 58mm x 26mm
  ** The O-ring of choice is 3/32" diameter (or .103" = 2.6mm) 
  ** The minimum Oring circumference, keeping it just outside the cell holder profile, is then 
  **  (58+5.2 + 29+5.2) * 2 = 188.8 mm, diameter = 60.1mm, = 2.366"
  ** Choose Dash Number 141, which is 2 1/2" OD. The circumference corresponding to the mean of the OD, ID is
  **     191.5 mm is the circumference of the oring
  ** To get to the actual profile, make the straight sides match the cell holder dimension:
  ** Remainder = 191.5 - (2 * (58 + 29)) = 17.5mm
  **  radius of a circle for that circumference is:  2.785mm
  */ 
  batt_holder_z_offset = 6;
  batt_holder_top_z_mm = 75;
  batt_holder_start_y_mm = 22; // will mirror to -y axis
  batt_holder_end_y_mm = 41;
  batt_holder_end_x_mm = 27;
  batt_holder_Ythick_mm = 5;
  batt_holder_Xthick_mm = 2;
  batt_holder_ywidth_mm = 10;
  batt_holder_brace_z_thick_mm = 14;
  oRingRadius = .103 * 25.4 * .5;
  cellFastenerDx = 6 * oRingRadius;
  AAcellW = 29;
  AAcellH = 58;
  oRingCellHolderRadius = 2.785;
  // 2 * (AAcellW + AAcellH) + 2 * pi * oRingCellHolderRadius = length of (i.e. circumference of) oring

  batt_holder_YZ_profile = [[batt_holder_start_y_mm, 0], 
                            [batt_holder_start_y_mm, batt_holder_top_z_mm],
                            [batt_holder_start_y_mm+batt_holder_ywidth_mm, batt_holder_top_z_mm],
                            [batt_holder_end_y_mm, batt_holder_brace_z_thick_mm],
                            [batt_holder_end_y_mm, 0]
                            ];

 
  batt_holder_XY_profile=[[batt_holder_end_x_mm, batt_holder_start_y_mm],
                          [batt_holder_end_x_mm, batt_holder_start_y_mm + batt_holder_Ythick_mm],
                          [-batt_holder_end_x_mm, batt_holder_start_y_mm + batt_holder_Ythick_mm],
                          [-batt_holder_end_x_mm, batt_holder_start_y_mm]];


/* number 2
  cellFastenNutHeight = .06 * 25.4;
  cellFastenBoltHoleDiameter = .09 * 25.4;
  cellFastenNutAcrossFlats = (3 / 16) * 25.4;
  cellFastenDriverClearanceDiameter = .13 * 25.4;
  cellFastenSocketHeadDiameter = .175 * 25.4;
  */

/* number 3 */
  cellFastenNutHeight = .07 * 25.4;
  cellFastenBoltHoleDiameter = .105 * 25.4;
  cellFastenNutAcrossFlats = .1865 * 25.4; // one thousandth's too small for tight fit
  cellFastenDriverClearanceDiameter = .115 * 25.4;
  cellFastenSocketHeadDiameter = .175 * 25.4;
/* */  

/* number 4 
  cellFastenNutHeight = .1 * 25.4;
  cellFastenBoltHoleDiameter = .12 * 25.4;
  cellFastenNutAcrossFlats = (1/4) * 25.4;
  cellFastenDriverClearanceDiameter = .145 * 25.4;
  cellFastenSocketHeadDiameter = .195 * 25.4;
  */

  minXFastener = -cellFastenerDx;
  minYFastener = -cellFastenerDx;
  maxYFastener = AAcellH + cellFastenerDx;
  maxXFastener = AAcellW + cellFastenerDx;
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

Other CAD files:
CAD/jig.FCStd

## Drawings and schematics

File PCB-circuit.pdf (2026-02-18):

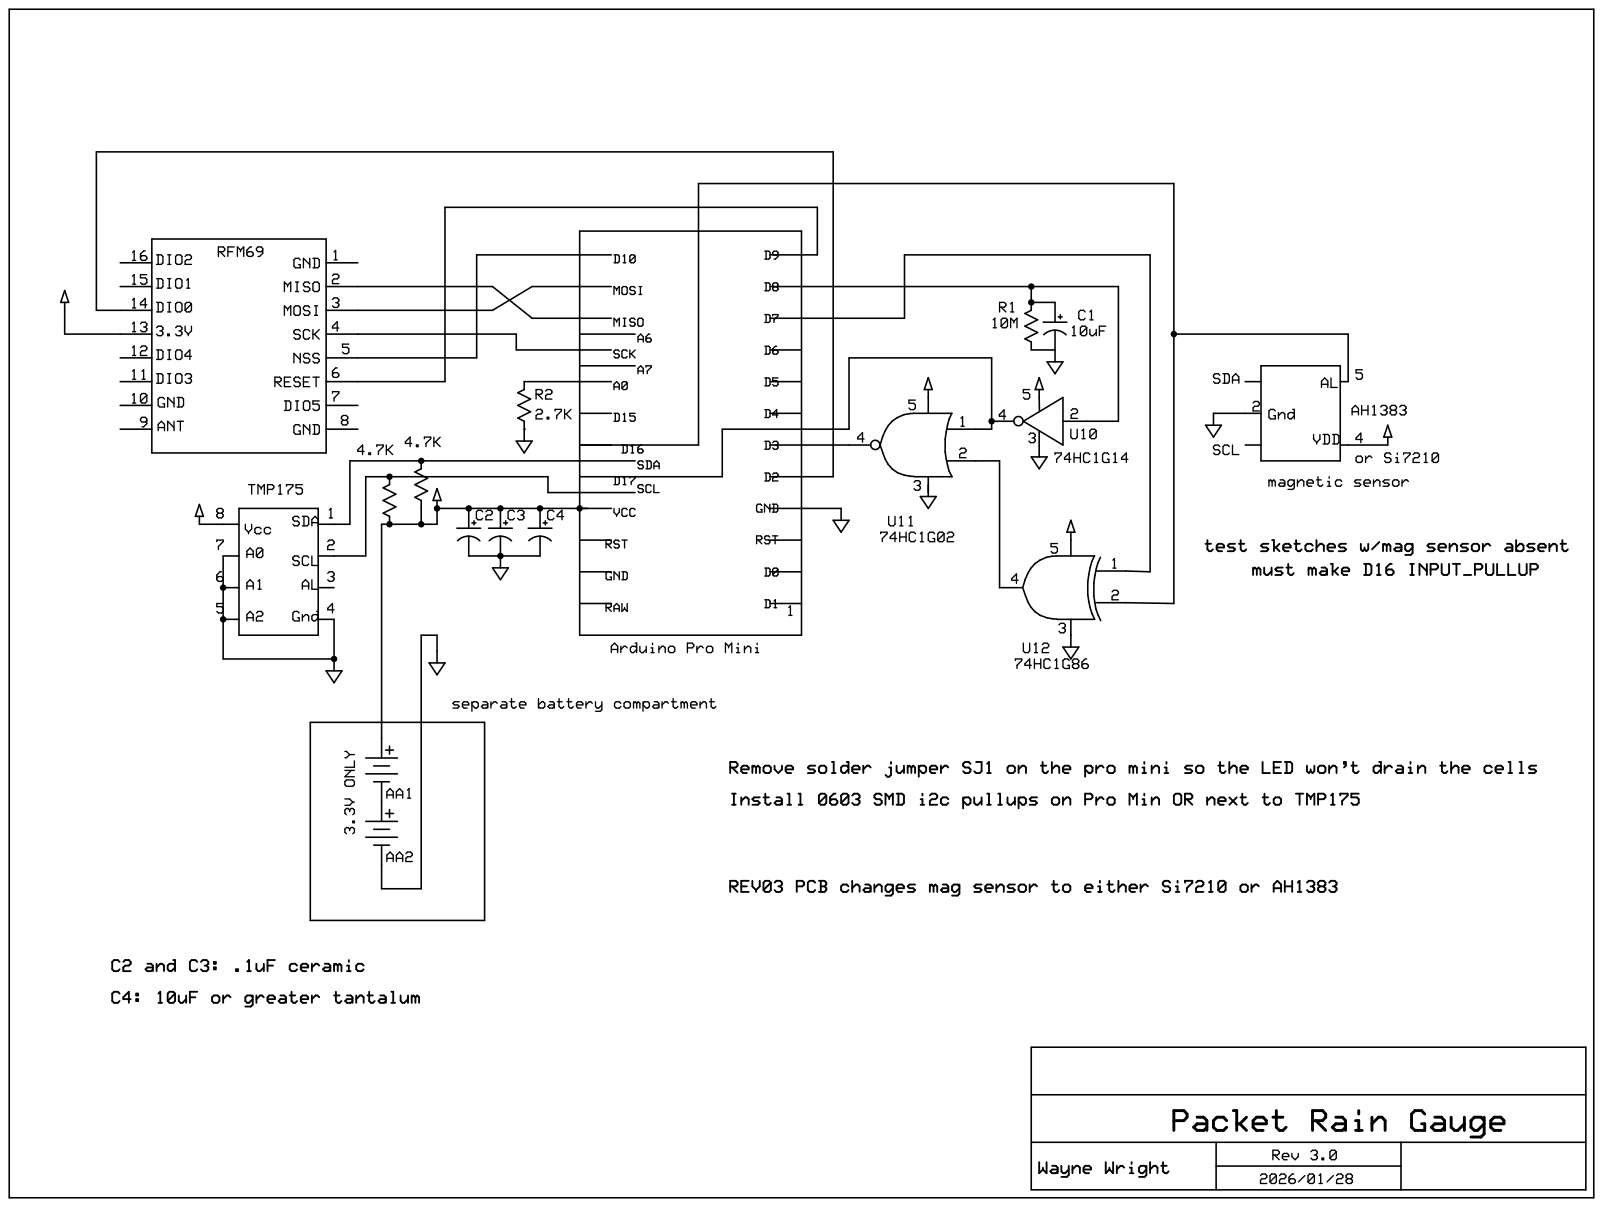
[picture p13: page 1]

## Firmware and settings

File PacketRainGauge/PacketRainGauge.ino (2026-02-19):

/* Packet rain gauge
* This sketch is to run on a Pro Mini on a PCB with a hall effect magnet sensor.
* It originates a packet for both the arrival and departure of a magnet
* to its sensor. The usual application is to mount a magnet on
* a rocker under a rain gauge funnel.
* 
* This design also reports a temperature from a TMP175 sensor and a battery 
* voltage level. It also originates packets on a timed interval in the absence of rainfail.
*/

#include <RadioConfiguration.h>
#include <SPI.h>
#include <EEPROM.h>
#include <Wire.h>
#include <avr/sleep.h>
#include <avr/interrupt.h>
#include <avr/power.h>
#include <RG-Si7210.h>
#include <RG-Tmp175.h>

// SparkFun's part numbers are:
// 915MHz:  https://www.sparkfun.com/products/13909
// 434MHz:  https://www.sparkfun.com/products/13910

// Parts of the code in this sketch are taken from these sparkfun pages,
// as are all the wiring instructions:
// https://learn.sparkfun.com/tutorials/rfm69hcw-hookup-guide

// Uses the RFM69 library by Felix Rusu, LowPowerLab.com
// Original library: https://github.com/LowPowerLab/RFM69

// Include the RFM69 and SPI libraries:
#define USE_RFM69
#define TELEMETER_BATTERY_V

// because the LED is on the SPI clock (SPK) line, access to the RFM69 flashes it dimly
//#define FLASH_LED_ON_STARTUP // for debugging. flashes it longer

#define FAR_THRESHOLD(X) (X)/32
#define NEAR_THRESHOLD(x) (x)/6

#define REVISION "REV09"
#define PCB_REV_NUMBER 3 // Sketch supports versions 2 or 3 only

// Only one of the following sensors may be defined
#define USE_AH1383
//#define USE_S7210

#if defined(USE_RFM69)
#include <RFM69.h>
#include <RFM69registers.h>
#endif

#if PCB_REV_NUMBER >= 3 || !defined(USE_AH1383)
#define EXPERIMENTAL_AH1383_ON_PCBV2 0
#else
/* Special case for the newly supported AH1383 on the older, Version 2 PCB.
** EXPERIMENTAL_AH1383_ON_PCBV2 is not a viable solution for permanent install because it telemeters 
** NOTHING while the bucket magnet is direcly over the sensor. But it works normally if the bucket 
** happens to come to rest at the stop far away from the magnet.*/
#define EXPERIMENTAL_AH1383_ON_PCBV2 1 
#endif

//signed/unsigned arithmetic is involved in timer compares and easy to get wrong
typedef  decltype(millis()) msec_time_stamp_t;
typedef  long msec_time_diff_t;
static_assert(sizeof(msec_time_diff_t) == sizeof(msec_time_stamp_t), "time stamp and time diff must have same precision");
template <typename D>
bool TimerCompleted(msec_time_stamp_t now, msec_time_stamp_t started, D interval)
{ return static_cast<msec_time_diff_t>(now - started) >= static_cast<msec_time_diff_t>(interval);}

class Pcb3Si7210
{   // The Si7210 is an I2C part that can read mag fields and has various parameters
    // Its "alert" output is wired to ROCKER_INPUT_PIN
 public:
    Pcb3Si7210() : si7210(0x33)
    {}
    bool isSleeping() const { return si7210.isSleeping();}
    bool isInterrupting();
    void wakeup() {  si7210.wakeup();}
    void one() {  si7210.one();}
    uint8_t sleep(bool fromOTP = true) { return si7210.sleep(fromOTP);}
    void resetToOTP() {  si7210.resetToOTP();}
    int16_t toggleOutputSense(){return si7210.toggleOutputSense();}
    uint16_t setSwHyst(uint8_t v){return si7210.setSwHyst(v);}
    uint16_t setSwOp(uint8_t v){return si7210.setSwOp(v);}

    void Setup();
    Si7210::MagField_t PollOutput();
    bool loop(unsigned long, bool &rainActivated, Si7210::MagField_t&magField);
    void dump(){ si7210.dump();}
protected:
    static uint16_t threshold(uint8_t sw_op) { return Si7210::threshold(sw_op);}
    static uint16_t hysteresis(uint8_t sw_hyst){return Si7210::hysteresis(sw_hyst);}
    Si7210::MagField_t readMagField(){return si7210.readMagField();}
    void setOutputSense(bool v){si7210.setOutputSense(v);}
    uint8_t getSwTamper(){return si7210.getSwTamper();}
     uint8_t getSwOp(){return si7210.getSwOp();}
    void SetupSwHyst(uint8_t hyst);
    void setFieldPolSel(uint8_t v){return si7210.setFieldPolSel(v);}
    uint8_t getSwHyst(){return si7210.getSwHyst();}
    static Si7210::MagField_t getMaxAmplitude(){return Si7210::getMaxAmplitude();}
    void FinishSetup();
    void SetupSwOp(uint8_t swop);
    void DoReadMode(unsigned long, Si7210::MagField_t);
    bool CheckThresholds(unsigned long now,Si7210::MagField_t);
    
    Si7210 si7210;
};

class Ah1383 {
    // The AH1383 is a hall effect uni-polar switch that is either ON or OFF,
    // which is read on the ROCKER_INPUT_PIN
    public:
    int16_t toggleOutputSense();
    bool loop(unsigned long, bool &rainActivated, Si7210::MagField_t&magField);
    void Setup(){};
    bool isInterrupting();
    uint16_t setSwOp(uint8_t v){return 0;}
    uint16_t setSwHyst(uint8_t v){return 0;}
    void resetToOTP(){}
    void wakeup(){}
    void one(){}
    uint8_t sleep(bool=false){return 0;}
    protected:
    void DoReadMode(unsigned long, Si7210::MagField_t);
};

#if defined(USE_AH1383)
typedef Ah1383 Sensor_t;
#elif defined(USE_S7210)
typedef Pcb3Si7210 Sensor_t;
#endif

namespace {
    enum class EepromAddresses {
        PACKET_RAINGAUGE_START = RadioConfiguration::EepromAddresses::TOTAL_EEPROM_USED,
        PACKET_RAINGAUGE_SLEEP_LOOP_COUNT = PACKET_RAINGAUGE_START,
        PACKET_RAINGAUGE_DISABLE_SERIAL = PACKET_RAINGAUGE_SLEEP_LOOP_COUNT + sizeof(unsigned),
        PACKET_RAINGAUGE_SWOP = PACKET_RAINGAUGE_DISABLE_SERIAL + 1,
        PACKET_RAINGAUGE_SWHYST = PACKET_RAINGAUGE_SWOP + 1,
        PACKET_RAINGAUGE_NEAR = PACKET_RAINGAUGE_SWHYST + 1,
        PACKET_RAINGAUGE_FAR = PACKET_RAINGAUGE_NEAR + sizeof(Si7210::MagField_t),
        PACKET_RAINGAUGE_SIGNED = PACKET_RAINGAUGE_FAR + sizeof(Si7210::MagField_t),
        PACKET_RAINGAUGE_END = PACKET_RAINGAUGE_SIGNED + 1
    };
    const int BATTERY_PIN = A0; // digitize (fraction of) battery voltage
    const int TIMER_RC_CHARGE_PIN = 8; // sleep uProc using RC circuit on this pin
    const int TXD_PIN = 1;
    const int RC_RLY_INTERRUPT_PIN = 3;
 #if PCB_REV_NUMBER >= 3
    const int RC_STATUS_PIN = 17;   // not used, but on REV02 of the PCB
    const int ROCKER_INPUT_PIN = 16;
#elif PCB_REV_NUMBER <= 2   // these pin assignments are reversed on REV02 vs REV03
    const int RC_STATUS_PIN = 16;
    const int ROCKER_INPUT_PIN = 17;
#endif
   const int SENSOR_INTERRUPT_INVERT_PIN = 7;

    /* The Pro Mini has only two interrupt pins that have the necessary features
    ** for responding to the three sources in this design, INT0 and INT1:
    ** 1. the RFM69
    ** 2. the R1/C1 sleep timer
    ** 3. the hall effect sensor AL pin that indicates the approach or departure of a magnet
    **
    ** The RFM69 is on INT0
    ** INT1 is shared by the RC circuit and the hall effect through the NOR at U11.
    ** Both signals are also routed to dedicated input pins on the Arduino, D17 and D16, respectively,
    ** so the interrupt handler on the sketch can distinguish the cause.
    */

    // after "listening" to Serial and RFM69 for as long as below, go to very low power sleep until INT0 or INT1
    const unsigned long FirstListenAfterTransmitMsec = 20000;// at system reset, listen Serial/RF for this long
    const unsigned long NormalListenAfterTransmit = 300;// after TX, go to RX for this long

#if defined(USE_RFM69)
// RFM69 frequency, uncomment the frequency of your module:

//#define FREQUENCY   RF69_433MHZ
#define FREQUENCY     RF69_915MHZ

// AES encryption (or not):
    const bool ENCRYPT = true; // Set to "true" to use encryption
    // Use ACKnowledge when sending messages (or not):
    const bool USEACK = true; // Request ACKs or not
    const int RFM69_RESET_PIN = 9;
    const int RFM69_CHIP_SELECT_PIN = 10;
    const int RFM69_INT_PIN = 2;
    const uint8_t GATEWAY_NODEID = 1;
 
    // Create a library object for our RFM69HCW module:
    RFM69 radio(RFM69_CHIP_SELECT_PIN, RFM69_INT_PIN, true);
#endif

    int16_t FarThreshold = FAR_THRESHOLD(Si7210::getMaxAmplitude());
    int16_t NearThreshold = NEAR_THRESHOLD(Si7210::getMaxAmplitude());
    uint8_t SignedThreshold = 0xff;

    bool getOnloopSerialDisable()
    {
        int addr = static_cast<uint16_t>(EepromAddresses::PACKET_RAINGAUGE_DISABLE_SERIAL);
        uint8_t ret = EEPROM.read(addr);
        if (ret == static_cast<uint8_t>(0xff))
            return 0;
        return ret != 0;
    }
    void setOnloopSerialDisable(bool b)
    {
        int addr = static_cast<uint16_t>(EepromAddresses::PACKET_RAINGAUGE_DISABLE_SERIAL);
        uint8_t v = b ? 1 : 0;
        EEPROM.write(addr, v);
    }
    uint8_t getRaingaugeSwop()
    {
        int addr = static_cast<uint16_t>(EepromAddresses::PACKET_RAINGAUGE_SWOP);
        return EEPROM.read(addr);
    }
    void setRaingaugeSwop(uint8_t v)
    {
        int addr = static_cast<uint16_t>(EepromAddresses::PACKET_RAINGAUGE_SWOP);
        EEPROM.write(addr, v);
    }
    uint8_t getRaingaugeSwHyst()
    {
        int addr = static_cast<uint16_t>(EepromAddresses::PACKET_RAINGAUGE_SWHYST);
        return EEPROM.read(addr);
    }
    void setRaingaugeSwHyst(uint8_t v)
    {
        int addr = static_cast<uint16_t>(EepromAddresses::PACKET_RAINGAUGE_SWHYST);
        EEPROM.write(addr, v);
    }
    void setNearThreshold(int16_t v)
    {
        int addr = static_cast<uint16_t>(EepromAddresses::PACKET_RAINGAUGE_NEAR);
        EEPROM.put(addr, v);
        NearThreshold = v;
    }
    void setFarThreshold(int16_t v)
    {
        int addr = static_cast<uint16_t>(EepromAddresses::PACKET_RAINGAUGE_FAR);
        EEPROM.put(addr, v);
        FarThreshold = v;
     }
    void setSignedThreshold(uint8_t v)
    {
        int addr = static_cast<uint16_t>(EepromAddresses::PACKET_RAINGAUGE_SIGNED);
        EEPROM.put(addr, v);
        SignedThreshold = v;
     }


#if defined(TELEMETER_BATTERY_V)
    void ResetAnalogReference();
#endif
    const unsigned MAX_SLEEP_LOOP_COUNT = 5000;
    const unsigned MONITOR_ROCKER_MSEC = 100; // go at least this long after waking before assuming it was RC was the cause
    const int MAX_WAIT_FOR_TOGGLE_MSEC = 100;
    const long SERIAL_PORT_BAUDS = 38400;
    const int MAX_MAGFIELD_POLL = 10;

    RadioConfiguration radioConfiguration;
    unsigned long TimeOfWakeup;
    unsigned SleepLoopTimerCount = 30; // approx R1 * C1 seconds per Count (= 100seconds)

    TMP175 tmp175(0b1001000); //0b1001000 per TMP175 docs, is I2C address with all addressing pins low.

    Sensor_t magSensor;
    bool prevSentMagnetClose;
    bool enableSerial = true;
    bool radioOK = false;
    auto ModeStart = millis();
    uint32_t ModeInterval;
    bool readMode = false;
}

namespace {
        const char SET_LOOPCOUNT[] = "SetDelayLoopCount";
        const char SET_SERIAL[] = "SetSerial";
        const char SET_THRESHOLD[] = "SetSWOP"; // HEX number range 00 : 7F where 7f is special case of "latch mode" where  
        const char SET_HYSTERESIS[] = "SetSWHYST"; // argument is HEX number range 00 : 3F, 3F is special case for ZERO
        const char SET_TOOTP[] = "SetToOTP";
        const char VER[] = "VER";
        const char DUMP_RFM69[] = "DumpRFM69";
        const char SET_SERIALONLOOP[] = "DisableSerialOnLoop";
        const char SET_NEAR_THRESHOLD[] = "SetNearThreshold";
        const char SET_FAR_THRESHOLD[] = "SetFarThreshold";
        const char SET_SIGNED_THRESHOLD[] = "SetSignedThreshold";
        const char READ_MODE_SECONDS[] = "ReadModeForSeconds";
}

void setup()
{
    // Open a serial port so we can send keystrokes to the module:
    enableSerial = true;
    Serial.begin(SERIAL_PORT_BAUDS);
    delay(100);
    Serial.print("Packet Rain Gauge " REVISION " for PCB V");
    Serial.println(static_cast<int>(PCB_REV_NUMBER));
    #if defined(USE_AH1383)
    Serial.println(F("AH1383 sensor"));
    #elif defined(USE_S7210)
    Serial.println(F("Si7210 sensor"));
    #endif
    Serial.print("Node ");
    Serial.print(radioConfiguration.NodeId(), DEC);
    Serial.print(" on network ");
    Serial.print(radioConfiguration.NetworkId(), DEC);
    Serial.print(" band ");
    Serial.print(radioConfiguration.FrequencyBandId(), DEC);
    Serial.print(" key ");
    radioConfiguration.printEncryptionKey(Serial);
    Serial.println(" ready");

#if defined(FLASH_LED_ON_STARTUP)
        pinMode(LED_BUILTIN, OUTPUT);
        for (int i = 0; i < 10; i++)
        {
        digitalWrite(LED_BUILTIN, HIGH);
        delay(100);
        digitalWrite(LED_BUILTIN, LOW);
        delay(100);
        }
        pinMode(LED_BUILTIN, INPUT);
#endif
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
void loop()
{
    static bool TransmittedSinceSleep = false;
    unsigned long now = millis();

#if defined(USE_RFM69)
    // RECEIVING
    // In this section, we'll check with the RFM69HCW to see
    // if it has received any packets:

    if (radioOK && radio.receiveDone()) // Got one!
    {
        // Print out the information:
        TimeOfWakeup = now; // extend sleep timer

        if (enableSerial)
        {
            Serial.print("received from node ");
            Serial.print(radio.SENDERID, DEC);
            Serial.print(", message [");

            // The actual message is contained in the DATA array,
            // and is DATALEN bytes in size:

            for (byte i = 0; i < radio.DATALEN; i++)
                Serial.print((char)radio.DATA[i]);

            // RSSI is the "Receive Signal Strength Indicator",
            // smaller numbers mean higher power.

            Serial.print("], RSSI ");
            Serial.println(radio.RSSI);
        }

        // RFM69 ensures trailing zero byte, unless buffer is full...so
        radio.DATA[sizeof(radio.DATA) - 1] = 0; // ...if buffer is full, ignore last byte
        if (processCommand((const char*)&radio.DATA[0]))
        {
            if (enableSerial)
                Serial.println("Received command accepted");
        }
        if (radio.ACKRequested())
        {
            radio.sendACK();
            if (enableSerial)
                Serial.println("ACK sent");
        }
    }
#endif
	
    // Set up a "buffer" for characters that we'll send:
    static char sendbuffer[62];
    static int sendlength = 0;
    // In this section, we'll gather serial characters and
    // send them to the other node if we (1) get a carriage return,
    // or (2) the buffer is full (61 characters).

    // If there is any serial input, add it to the buffer:

    while (enableSerial && Serial.available() > 0)
    {
        TimeOfWakeup = now; // extend timer while we hear something
        char input = Serial.read();

        if (input != '\r') // not a carriage return
        {
            sendbuffer[sendlength] = input;
            sendlength++;
        }

        // If the input is a carriage return, or the buffer is full:
        if ((input == '\r') || (sendlength == sizeof(sendbuffer) - 1)) // CR or buffer full
        {
            sendbuffer[sendlength] = 0;
            if (processCommand(sendbuffer))
            {
                if (enableSerial)
                {
                    Serial.print(sendbuffer);
                    Serial.println(" command accepted for rain gauge");
                }
            }
            else if (radioConfiguration.ApplyCommand(sendbuffer))
            {
                if (enableSerial)
                {
                    Serial.print(sendbuffer);
                    Serial.println(" command accepted for radio");
                }
            }
            if (enableSerial)
                Serial.println("ready");
            sendlength = 0; // reset the packet
        }
    }
   
    bool rainActivated = MonitorRockerInput(now);
    
    Si7210::MagField_t magField = 0;
    if (magSensor.loop(now, rainActivated, magField))
        return; // not ready. loop() again

    if (rainActivated ||
        (!TransmittedSinceSleep && TimerCompleted(now , TimeOfWakeup, MONITOR_ROCKER_MSEC)))
    { 
        TransmittedSinceSleep = true; /* Transmit at least once per wakeup. */
        int batt(0);
#if defined(TELEMETER_BATTERY_V)
        // 10K to VCC and (wired on board) 2.7K to ground
        pinMode(BATTERY_PIN, INPUT_PULLUP); // sample the battery
        batt = analogRead(BATTERY_PIN);
        /* batt result means little in absolute terms, but its
        ** history is telling. Failing cells have a pattern.*/
        pinMode(BATTERY_PIN, INPUT); // turn off battery drain
#endif
        // read temperature data
        auto temperature = tmp175.finishReadTempCx16();

        char sign = '+';
        if (temperature < 0) {
            temperature = -temperature;
            sign = '-';
        }
        else if (temperature == 0.f)
            sign = ' ';

        int whole = temperature >> 4;
        int frac = temperature & 0xF;
        frac *= 100;
        frac >>= 4;

        static char buf[64];
        sprintf(buf, "C:%u, B:%d, T:%c%d.%02d, RG: %d F: %d",
            sampleCount++,
            batt,
            sign, whole,
            frac,
            static_cast<int>(rainActivated ? 1 : 0),
            static_cast<int>(magField)
        );
        if (enableSerial)
            Serial.println(buf);
#if defined(USE_RFM69) 
        if (radioOK)
            radio.sendWithRetry(GATEWAY_NODEID, buf, strlen(buf));
#endif
    }

    if (TimerCompleted(now, TimeOfWakeup, ListenAfterTransmitMsec))
    {	// go to sleep. with R1/C1 as specified will be about 100 seconds
        TransmittedSinceSleep = false;
        if (getOnloopSerialDisable())
            SetSerialEnabled(false);
        SleepTilNextInterrupt();
        TimeOfWakeup = millis();
        ListenAfterTransmitMsec = NormalListenAfterTransmit;
    }
}

void sleepPinInterrupt()	// requires 10uF and 10M between two pins
{
    // run at interrupt level. disables further interrupt from this source
    detachInterrupt(digitalPinToInterrupt(RC_RLY_INTERRUPT_PIN));
}

namespace {
    unsigned SleepTilNextInterrupt()
    {
        if (enableSerial)
        {
            Serial.print("sleep for count=");
            Serial.println(SleepLoopTimerCount);
            Serial.flush();// wait for finish and turn off pins before sleep
            Serial.end();
        }
        // regardless of whether the Serial is going to be re-enabled, hold TX steady
        // so if a port is attached, the PC doesn't get (as much) garbage.
        pinMode(0, INPUT); // Arduino libraries have a symbolic definition for Serial pins?
        digitalWrite(TXD_PIN, HIGH);
        pinMode(TXD_PIN, OUTPUT); // TXD hold steady

#if defined(USE_RFM69)
        if (radioOK)
            radio.sleep();
#endif

#if defined(TELEMETER_BATTERY_V)
        auto saveADCSRA = ADCSRA;
        ADCSRA = 0; // Turn off ADC
#endif

        magSensor.sleep(false);

        power_all_disable(); // turn off everything

        unsigned count = 0;

        // this uses R1 and C1 to ground
        while (count < SleepLoopTimerCount)
        {
            #if EXPERIMENTAL_AH1383_ON_PCBV2==0 // this is the "normal" code. Test code is below
            if (magSensor.isInterrupting())
                break;
            power_timer0_enable(); // delay() requires this
            pinMode(TIMER_RC_CHARGE_PIN, OUTPUT);
            digitalWrite(TIMER_RC_CHARGE_PIN, HIGH);
            delay(10); // Charge the Cap (1uF to 10uF)
            pinMode(TIMER_RC_CHARGE_PIN, INPUT);
            cli();
            power_timer0_disable(); // timer0 powered down again
            attachInterrupt(digitalPinToInterrupt(RC_RLY_INTERRUPT_PIN), sleepPinInterrupt, LOW);         
            
            #else  /*Testing an AH1383 on the older PCB
            ** The RC based transmit events only happen with the bucket magnet AWAY.
            ** While the magnet is close, we sleep waiting for the interrupt on HIGH level, */
            bool hallEffectActive = digitalRead(ROCKER_INPUT_PIN) == LOW;
            power_timer0_enable(); // delay() requires this
            pinMode(TIMER_RC_CHARGE_PIN, OUTPUT);
            digitalWrite(TIMER_RC_CHARGE_PIN, HIGH);
            delay(10); // Charge the 1uF
            if (!hallEffectActive) // Disable the RC timer while hall effect active
                pinMode(TIMER_RC_CHARGE_PIN, INPUT);
            cli();
            power_timer0_disable(); // timer0 powered down again
            attachInterrupt(digitalPinToInterrupt(RC_RLY_INTERRUPT_PIN), sleepPinInterrupt, hallEffectActive? HIGH: LOW);
            #endif

            set_sleep_mode(SLEEP_MODE_PWR_DOWN);
            sleep_enable();
            sleep_bod_disable();
            sei();
            sleep_cpu(); 
            sleep_disable();
            sei();
            count += 1;
        }

        power_all_enable();

#if defined(TELEMETER_BATTERY_V)
        ADCSRA = saveADCSRA;
        ResetAnalogReference();
#endif

        if (enableSerial)
        {
            Serial.begin(SERIAL_PORT_BAUDS);
            Serial.println(F("******waked up*******"));
        }

        tmp175.startReadTemperature();
        magSensor.wakeup();
        magSensor.one(); // Output pin check won't be updated in loop() without this
        return count;
    }

#if defined(TELEMETER_BATTERY_V)
	void ResetAnalogReference()
	{
		analogReference(INTERNAL);
		pinMode(BATTERY_PIN, INPUT);
		analogRead(BATTERY_PIN);
		delay(10); // let ADC settle
	}
#endif
}
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

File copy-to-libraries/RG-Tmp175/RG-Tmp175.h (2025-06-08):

#pragma once
// 2wire interface for TMP175 temperature sensor
class TMP175 {
public:
    TMP175(uint8_t addr, unsigned SettleTimeMsec = SETTLE_TIME_MSEC) : SlaveAddress(addr), SettleTimeMsec(SettleTimeMsec)
    {}

    void startReadTemperature()
    {
        Wire.beginTransmission(SlaveAddress);
        writePointerRegister(CONFIGURATION_REG);
        // R0 without R1 means 10 bit conversion (1/4 degree C) in 55msec
        // OS means one-shot
        // SD means shut down immediately after the one-shot conversion
        uint8_t config = OS | SD | R0;
        Wire.write(config);
        Wire.endTransmission(); 
        MsecWhenStartedTemperature = millis();
    }

    int16_t finishReadTempCx16()
    {
        long tmp175Delay = millis() - MsecWhenStartedTemperature;
        tmp175Delay = static_cast<long>(SettleTimeMsec) - tmp175Delay;
        if (tmp175Delay > 0)
            delay(tmp175Delay);

        Wire.beginTransmission(SlaveAddress);
        writePointerRegister(TEMPERATURE_REG);
        Wire.endTransmission(false);

        int16_t tempCtimes256 = 0;
        static const uint8_t READ_TEMPERATURE_BYTE_COUNT = 2;
        Wire.requestFrom(SlaveAddress, READ_TEMPERATURE_BYTE_COUNT);
        for (int i = 0; i < READ_TEMPERATURE_BYTE_COUNT; i++)
        {
            if (Wire.available())
            {
                unsigned char v = Wire.read();
                tempCtimes256 <<= 8;
                tempCtimes256 |= v;
            }
            else
                return 0xFFFF;
        }
        return tempCtimes256 >> 4;
    }

    void delayForADC()
    {
        delay(SettleTimeMsec); // let temperature ADC settle--depends on R0/R1
    }

    int16_t readTempCx16()
    {
        startReadTemperature();
        delayForADC();
        return finishReadTempCx16();
    }
    float scale() const { return 1/16.f;}
    void setup()
    {
        Wire.beginTransmission(SlaveAddress);
        writePointerRegister(CONFIGURATION_REG);
        uint8_t config = SD; // set shutdown mode to minimize battery drain
        Wire.write(config);
        Wire.endTransmission();
    }

    void dump()
    {
        for (int i = 0; i < NUM_POINTERS; i += 1)
        {
            Wire.beginTransmission(SlaveAddress);
            writePointerRegister(static_cast<Pointer_t>(i));
            Wire.endTransmission(false);
            Wire.requestFrom(SlaveAddress, static_cast<uint8_t>(2));
            Serial.print("Dump config="); 
            Serial.println(i);
            while (Wire.available())
            {
                Serial.print(" 0x"); 
                Serial.print((int)Wire.read(), HEX);
            }
            Serial.println();
        }
    }
private:
    enum {SETTLE_TIME_MSEC = 60 };
    const uint8_t SlaveAddress;
    enum Pointer_t { TEMPERATURE_REG, CONFIGURATION_REG, T_LOW_REG, T_HIGH_REG, NUM_POINTERS};
    enum Configuration_t {
        SD = 1, TM = 1 << 1, POL = 1 << 2,
        F0 = 1 << 3, F1 = 1 << 4,
        R0 = 1 << 5, R1 = 1 << 6, OS = 1 << 7
    };
    void writePointerRegister(Pointer_t pointerReg)
    {
        Wire.write(static_cast<uint8_t>(pointerReg));
    }
    unsigned long MsecWhenStartedTemperature;
    unsigned SettleTimeMsec;
};

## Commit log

2022-09-16 prelimanary tests complete
    [base.stl, enclosure.cfg, lid.stl]
2022-09-25 as built
    [calibration cylinder.stl]
2022-10-18 withhold reporting on mag field interrupt without enough amplitude
2023-04-21 tmp175 wait time correction
    [RG-Tmp175.h]
2023-10-28 better grounds
2023-11-04 more convenient i2c pull up install on PCB
2025-05-30 Outdoor unit remix
    [Pluviometer.scad, base.stl, calibration cylinder.stl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]
2025-05-30 PCB update
    [pcb.sch]
2025-06-02 documentation update
    [Pluviometer.scad]
2025-06-08 testing snapshot
    [jig.FCStd]
2025-06-08 PCB schematic update
    [pcb.sch]
2025-06-08 schematic cosmetics
    [pcb.sch]
2025-10-09 ADC save/restore
2025-10-19 encloser blocks RESET switch
2026-01-25 improved bucket and funnel
    [Pluviometer.scad]
2026-01-25 Revise rainfall measurement and update design details
    Updated rainfall measurement details and added information about the new weighting nut for consistency.
2026-01-28 handle magnet sense details much more reliably
    [enclosure.cfg]
2026-02-18 3D print orientation of support enforcer
    [Pluviometer.scad]
2026-02-18 ah1383 support
    [pcb.sch]
